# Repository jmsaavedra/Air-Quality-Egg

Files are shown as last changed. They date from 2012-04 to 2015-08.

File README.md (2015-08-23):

# Air Quality Egg

A large-scale distributed air quality network sensor device. based on the Nanode
an Arduino-compatible, Ethernet enabled microcontroller.
[airqualityegg.com](http://airqualityegg.com)

## Sensors
* temp/humidity (RHT22)
* carbon monoxide (e2v MICS-5525)
* nitrous dioxide (e2v MICS-2710)

## Notes
* auto reset feature connects digitalPin 3 to RESET pin
** this *must* be disconnected when programming the board.

## Collaborators
* [cosm.com](http://cosm.com)
* [citizensensor.cc](http://citizensensor.cc) | [jos.ph](http://jos.ph)
* [Wicked Device](http://wickeddevice.com)
* Ricardo Piedrahita, Nick Masson - UC Boulder (-link-)
* your name here

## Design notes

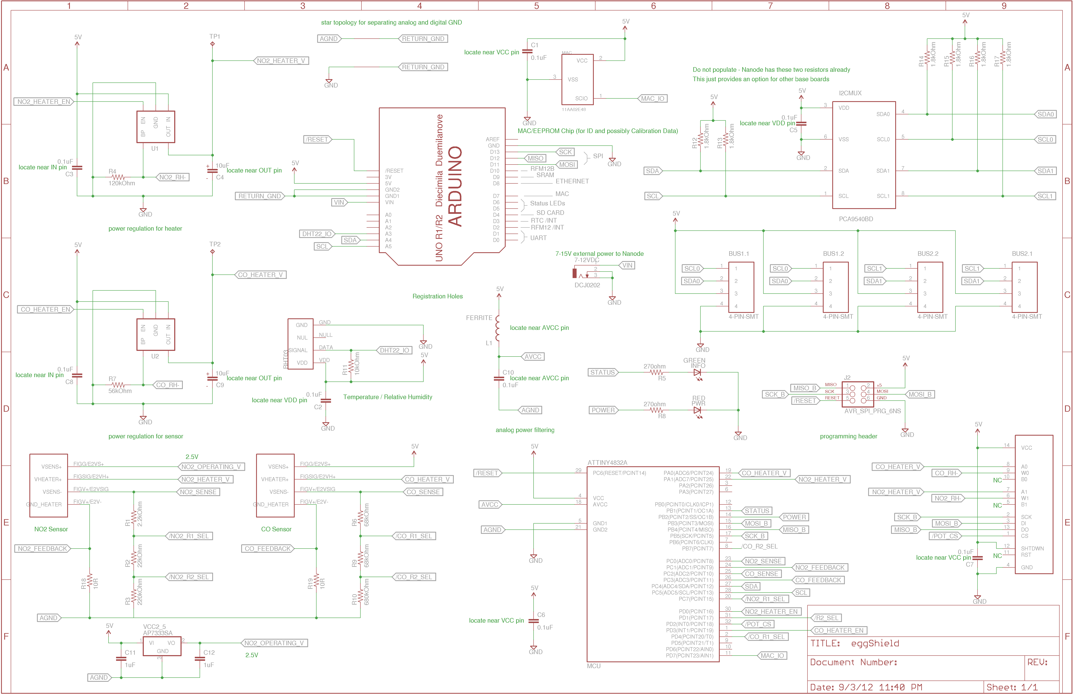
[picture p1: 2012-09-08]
.solderpad/schematic.png

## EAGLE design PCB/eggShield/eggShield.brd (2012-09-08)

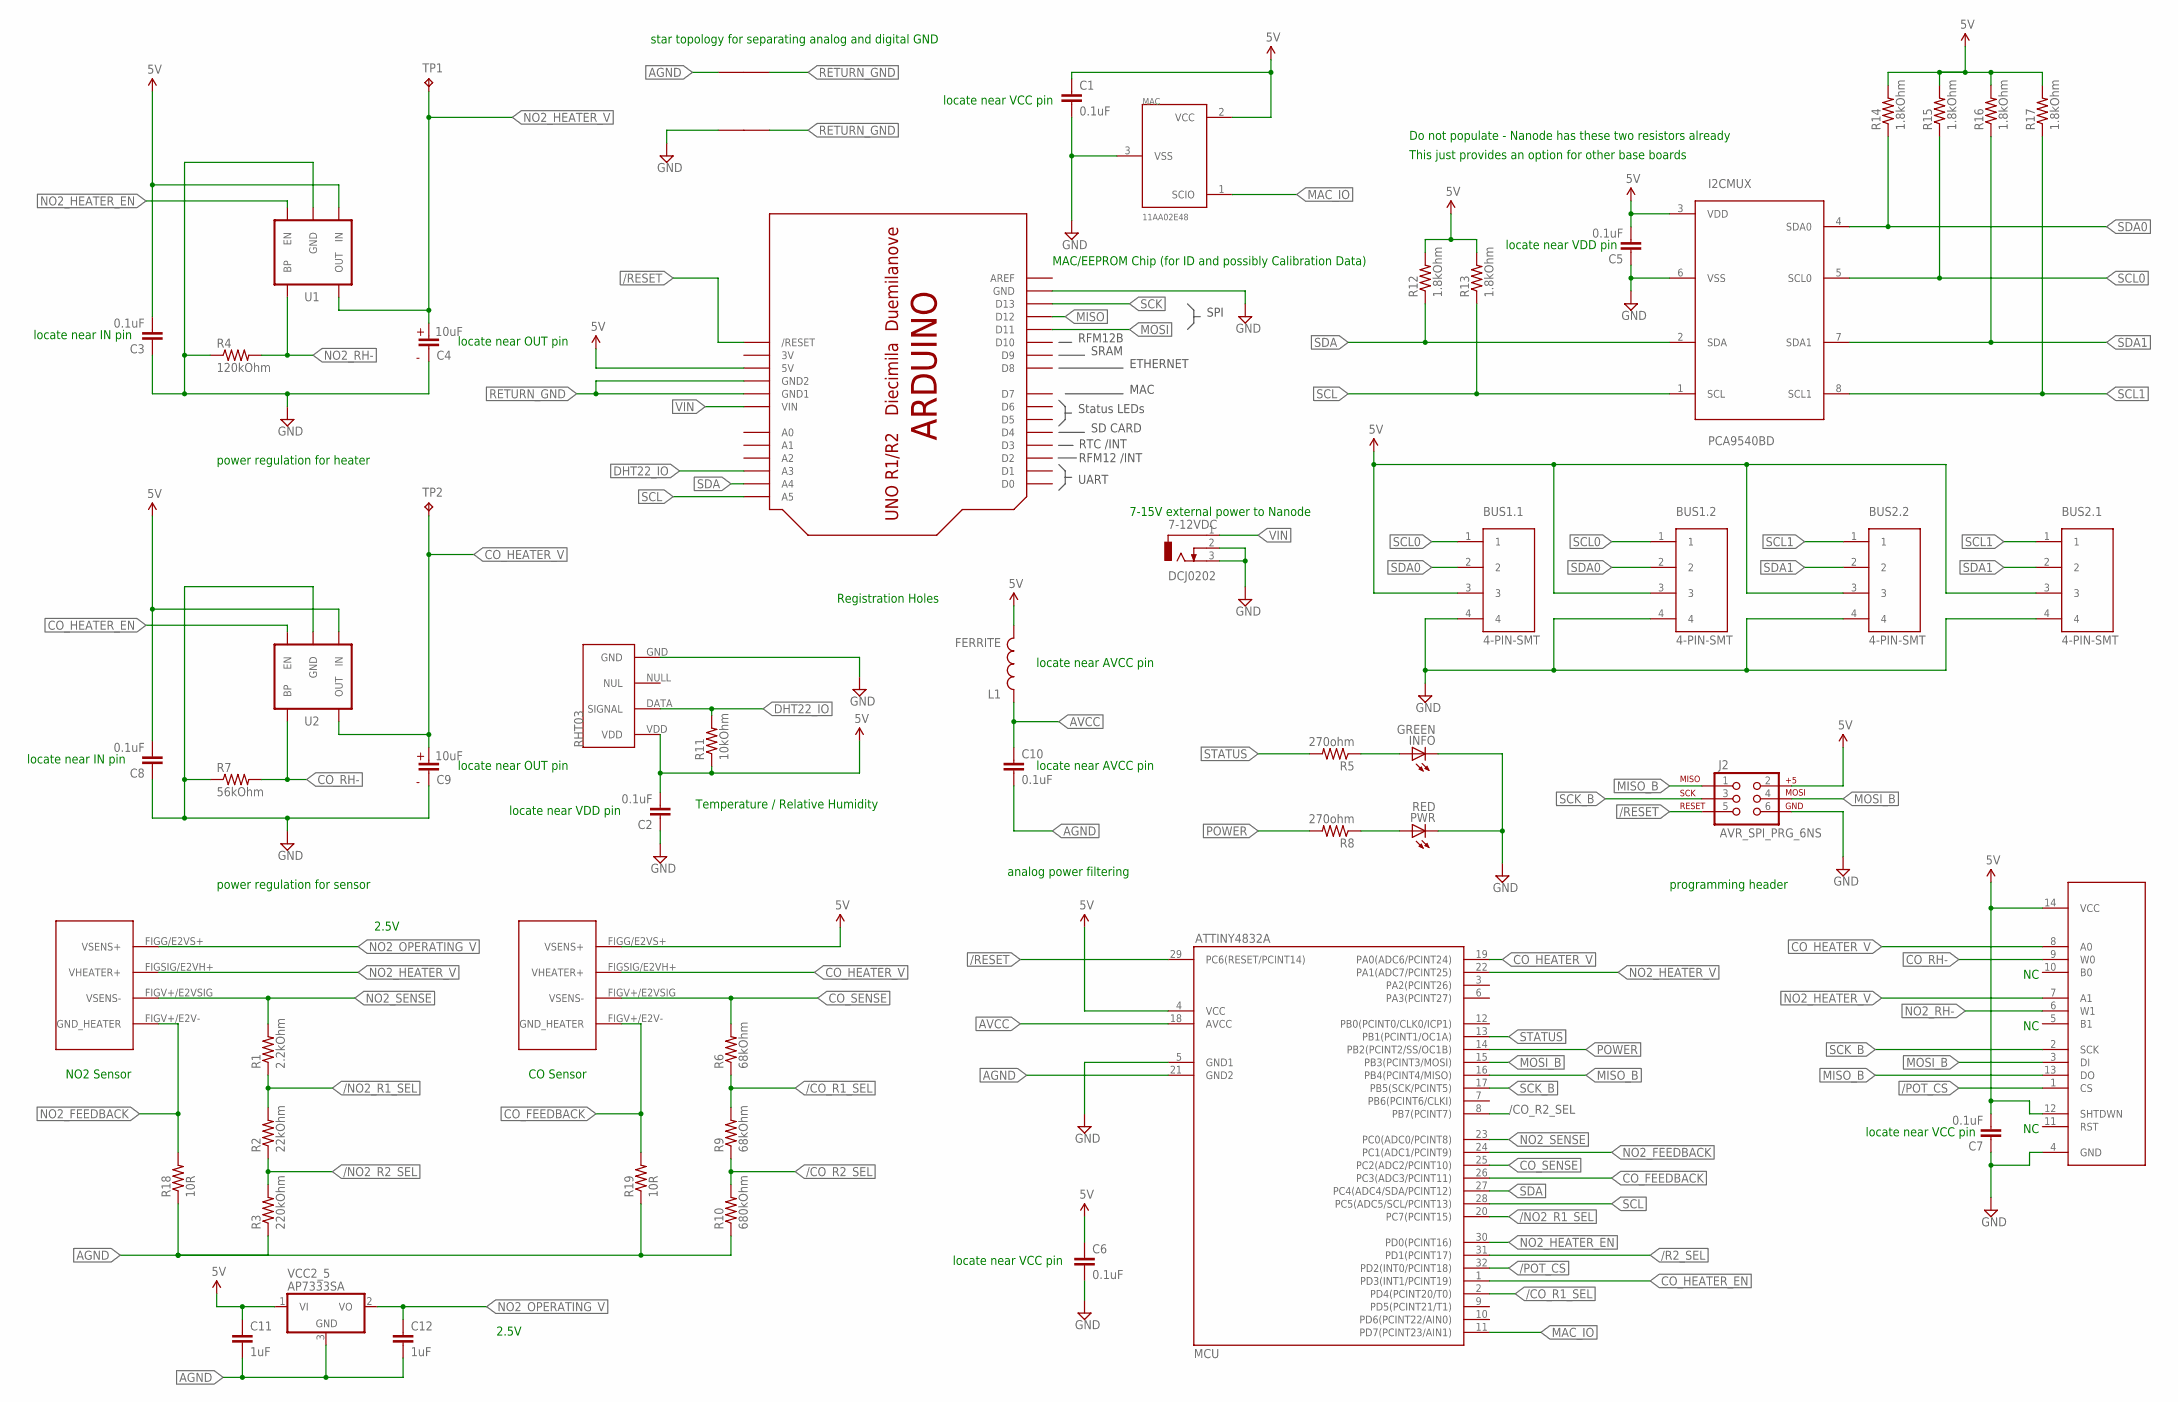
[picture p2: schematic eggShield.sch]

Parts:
7-12VDC: DCJ0202
BUS1.1, BUS1.2, BUS2.1, BUS2.2: 4-PIN-SMT; 1775470-4
C1, C2, C3, C5, C6, C7, C8, C10: 0.1uF; 0805
C4, C9: 10uF; TYPE-B_ALUMINUM_CAN
C11, C12: 1uF; 0805
CO: E2V; SR-4
DHT22: RHT03; 1X04_LOCK
I2CMUX: PCA9540BD; SO8
INFO: GREEN; CHIPLED_0805
J2: AVR_SPI_PRG_6NS; 2X3-NS
L1: FERRITE; 0805
MAC: 11AA02E48; SOT23
MCU: ATTINY4832A; TQFP32-08
N02: E2V; SR-4
PWR: RED; CHIPLED_0805
R1: 2.2kOhm; 0805
R2: 22kOhm; 0805
R3: 220kOhm; 0805
R4: 120kOhm; 0805
R5, R8: 270ohm; 0805
R6, R9: 68kOhm; 0805
R7: 56kOhm; 0805
R10: 680kOhm; 0805
R11: 10kOhm; 0805
R12, R13, R14, R15, R16, R17: 1.8kOhm; 0805
R18, R19: 10R; 0805
TP1, TP2: TPPAD1-13; P1-13
U1, U2: V_REG_LDOSMD; SOT23-5
U3: MCP42XXX; SO014
U$7: ARDUINO-NOHOLE
U$13, U$14: PLANE_COUPLER
VCC2_5: AP7333SA; SOT-23-3

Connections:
3V: U$7.3V
5V: BUS1.1.3, BUS1.2.3, BUS2.1.3, BUS2.2.3, C1.1, C2.2, C3.2, C5.2, C6.1, C7.2, C8.2, C11.1, CO.FIGG/E2VS+ (VSENS+), DHT22.VDD, I2CMUX.3 (VDD), J2.2, L1.2, MAC.2 (VCC), MCU.4 (VCC), R11.1, R12.2, R13.2, R14.2, R15.2, R16.2, R17.2, U1.1 (IN), U2.1 (IN), U3.12 (SHTDWN), U3.14 (VCC), U$7.5V, VCC2_5.1 (VI)
/CO_R1_SEL: MCU.2 (PD4(PCINT20/T0)), R6.1, R9.2
/CO_R2_SEL: MCU.8 (PB7(PCINT7)), R9.1, R10.2
/NO2_R1_SEL: MCU.20 (PC7(PCINT15)), R1.1, R2.2
/NO2_R2_SEL: R2.1, R3.2
/POT_CS: MCU.32 (PD2(INT0/PCINT18)), U3.1 (CS)
/R2_SEL: MCU.31 (PD1(PCINT17))
/RESET: J2.5, MCU.29 (PC6(RESET/PCINT14)), U$7.RESET (/RESET)
AGND: C10.2, C11.2, C12.2, MCU.21 (GND2), R3.1, R10.1, R18.1, R19.1, U$13.1, VCC2_5.3 (GND)
AVCC: C10.1, L1.1, MCU.18 (AVCC)
CO_FEEDBACK: CO.FIGV+/E2V- (GND_HEATER), MCU.26 (PC3(ADC3/PCINT11)), R19.2
CO_HEATER_EN: MCU.1 (PD3(INT1/PCINT19)), U2.3 (EN)
CO_HEATER_V: C9.P$1 (1), CO.FIGSIG/E2VH+ (VHEATER+), MCU.19 (PA0(ADC6/PCINT24)), TP2.TP, U2.5 (OUT), U3.8 (A0)
CO_RH-: R7.2, U2.4 (BP), U3.9 (W0)
CO_SENSE: CO.FIGV+/E2VSIG (VSENS-), MCU.25 (PC2(ADC2/PCINT10)), R6.2
DHT22_IO: DHT22.DATA (SIGNAL), R11.2, U$7.A3
GND: 7-12VDC.2, 7-12VDC.3, BUS1.1.4, BUS1.2.4, BUS2.1.4, BUS2.2.4, C1.2, C2.1, C3.1, C4.P$2 (2), C5.1, C6.2, C7.1, C8.1, C9.P$2 (2), DHT22.GND, I2CMUX.6 (VSS), INFO.C, J2.6, MAC.3 (VSS), MCU.5 (GND1), PWR.C, R4.1, R7.1, U1.2 (GND), U2.2 (GND), U3.4 (GND), U$7.GND, U$14.1
MAC_IO: MAC.1 (SCIO), MCU.11 (PD7(PCINT23/AIN1))
MISO: U$7.D12
MISO_B: J2.1, MCU.16 (PB4(PCINT4/MISO)), U3.13 (DO)
MOSI: U$7.D11
MOSI_B: J2.4, MCU.15 (PB3(PCINT3/MOSI)), U3.3 (DI)
unnamed: INFO.A, R5.1
unnamed: PWR.A, R8.1
NO2_FEEDBACK: MCU.24 (PC1(ADC1/PCINT9)), N02.FIGV+/E2V- (GND_HEATER), R18.2
NO2_HEATER_EN: MCU.30 (PD0(PCINT16)), U1.3 (EN)
NO2_HEATER_V: C4.P$1 (1), MCU.22 (PA1(ADC7/PCINT25)), N02.FIGSIG/E2VH+ (VHEATER+), TP1.TP, U1.5 (OUT), U3.7 (A1)
NO2_OPERATING_V: C12.1, N02.FIGG/E2VS+ (VSENS+), VCC2_5.2 (VO)
NO2_RH-: R4.2, U1.4 (BP), U3.6 (W1)
NO2_SENSE: MCU.23 (PC0(ADC0/PCINT8)), N02.FIGV+/E2VSIG (VSENS-), R1.2
POWER: MCU.14 (PB2(PCINT2/SS/OC1B)), R8.2
RETURN_GND: U$7.GND1, U$7.GND2, U$13.2, U$14.2
SCK: U$7.D13
SCK_B: J2.3, MCU.17 (PB5(SCK/PCINT5)), U3.2 (SCK)
SCL: I2CMUX.1 (SCL), MCU.28 (PC5(ADC5/SCL/PCINT13)), R13.1, U$7.A5
SCL0: BUS1.1.1, BUS1.2.1, I2CMUX.5 (SCL0), R15.1
SCL1: BUS2.1.1, BUS2.2.1, I2CMUX.8 (SCL1), R17.1
SDA: I2CMUX.2 (SDA), MCU.27 (PC4(ADC4/SDA/PCINT12)), R12.1, U$7.A4
SDA0: BUS1.1.2, BUS1.2.2, I2CMUX.4 (SDA0), R14.1
SDA1: BUS2.1.2, BUS2.2.2, I2CMUX.7 (SDA1), R16.1
STATUS: MCU.13 (PB1(PCINT1/OC1A)), R5.2
VIN: 7-12VDC.1, U$7.VIN

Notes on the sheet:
power regulation for heater
NO2 Sensor
10uF
power regulation for sensor
locate near IN pin
locate near OUT pin
CO Sensor
Temperature / Relative Humidity
locate near VDD pin
Do not populate - Nanode has these two resistors already
This just provides an option for other base boards
SPI
SRAM
ETHERNET
SD CARD
MAC
Status LEDs
RFM12B
UART
Registration Holes
locate near VCC pin
star topology for separating analog and digital GND
locate near AVCC pin
analog power filtering
2.5V
programming header
7-15V external power to Nanode
RFM12 /INT
RTC /INT
MAC/EEPROM Chip (for ID and possibly Calibration Data)

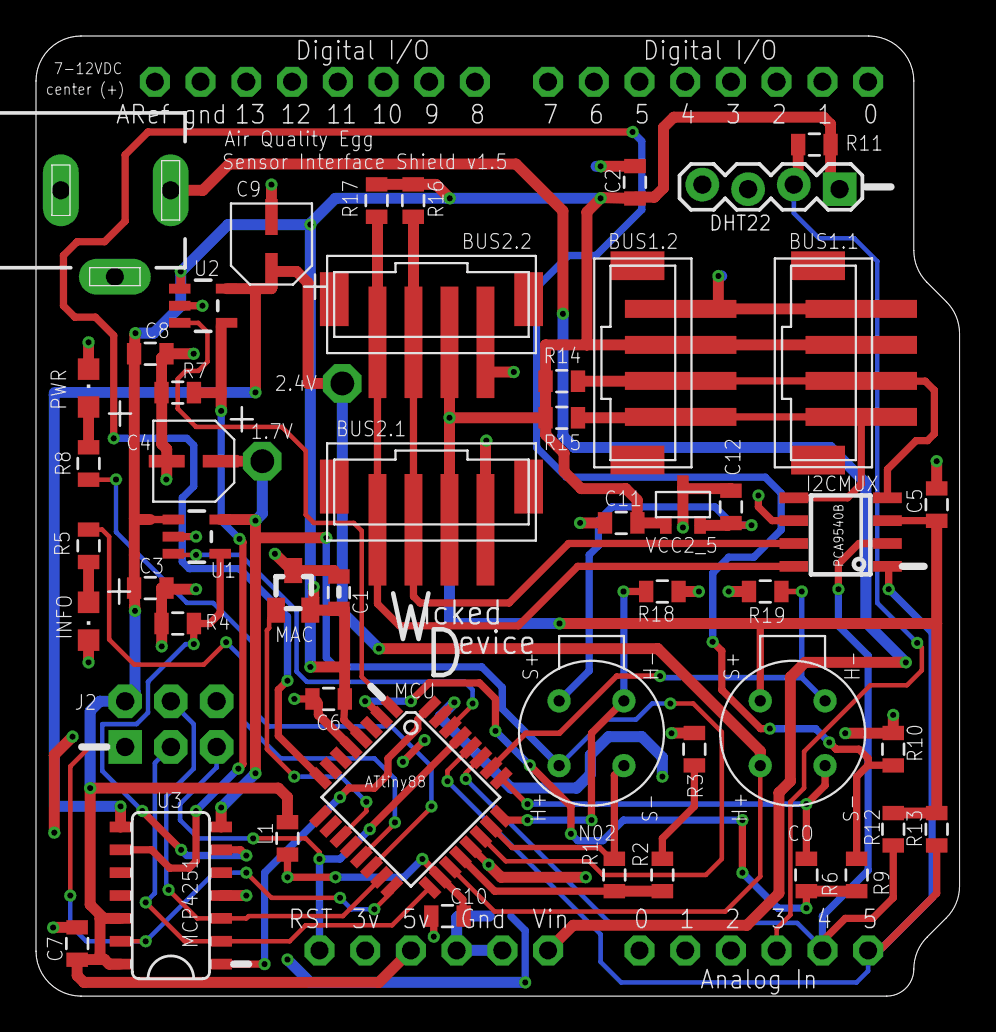
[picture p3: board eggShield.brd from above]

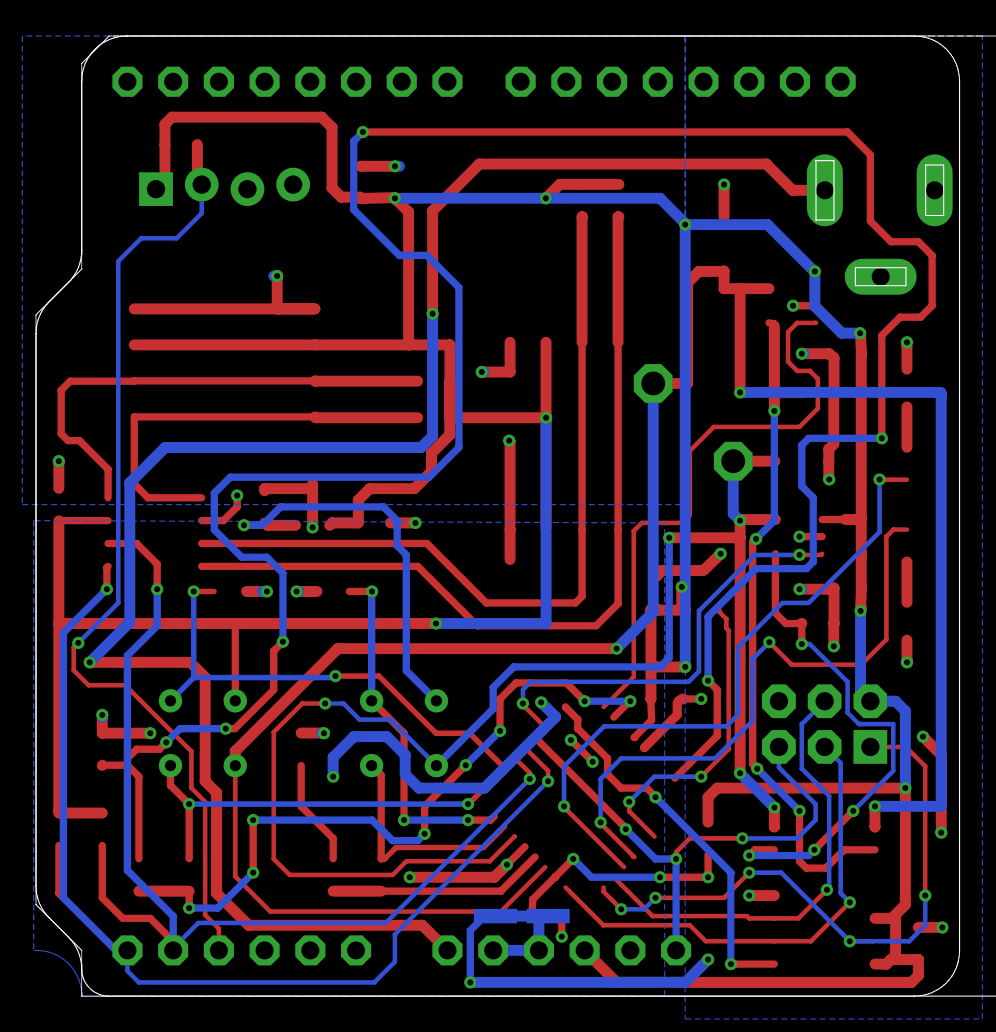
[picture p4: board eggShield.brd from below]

Board: 2 copper layers, 51.3 x 53.3 mm, 55 parts (2 on the bottom side), 38 nets.

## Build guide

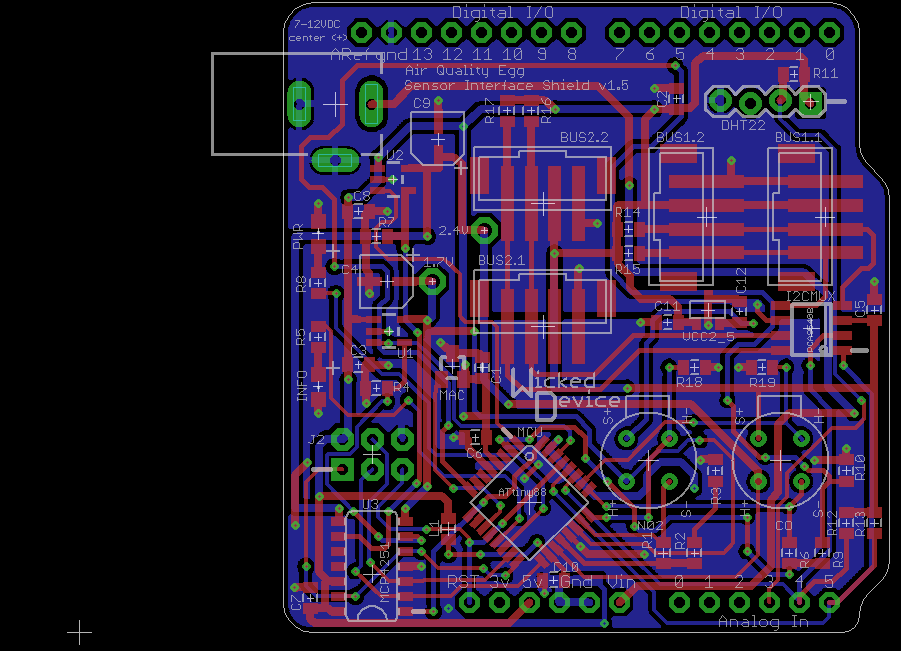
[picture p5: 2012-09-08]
.solderpad/board.png

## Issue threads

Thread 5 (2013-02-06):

Sensor doesn't reconnect without power cycling both units

yaleman, 2013-02-06:
Is there a way to fix this issue? Having to power cycle both units to get them back online seems counterintuitive.

I see from the serial logs that the sensor can seemingly know its previous base station and look for that, but it doesn't send data for some reason. Is this a known issue or a new one?

yaleman, 2021-01-08:
guess not.

Closed 2021-01-08.

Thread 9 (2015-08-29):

compile errors

grenm, 2015-08-29:
Hi, new to arduino programming, following the https://vimeo.com/58550465 Egg-3Reprogramming guide closely, the AQEBase will not compile, screen print below

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

- I am certainly doing something silly, any tips? Compile error messages below:

Arduino: 1.6.5 (Windows 7), Board: "Arduino/Genuino Uno"

In file included from AQEBase.ino:4:0:
C:\Users\ggren\Documents\Arduino\libraries\EtherCard/EtherCard.h:290:28: error: 'prog_char' has not been declared
     static void browseUrl (prog_char *urlbuf, const char *urlbuf_varpart,
                            ^
C:\Users\ggren\Documents\Arduino\libraries\EtherCard/EtherCard.h:291:28: error: 'prog_char' has not been declared
                            prog_char *hoststr, const prog_char *additionalheaderline,
                            ^
C:\Users\ggren\Documents\Arduino\libraries\EtherCard/EtherCard.h:291:54: error: 'prog_char' does not name a type
                            prog_char *hoststr, const prog_char *additionalheaderline,
                                                      ^
C:\Users\ggren\Documents\Arduino\libraries\EtherCard/EtherCard.h:291:65: error: ISO C++ forbids declaration of 'additionalheaderline' with no type [-fpermissive]
                            prog_char *hoststr, const prog_char *additionalheaderline,
                                                                 ^
C:\Users\ggren\Documents\Arduino\libraries\EtherCard/EtherCard.h:297:28: error: 'prog_char' has not been declared
     static void browseUrl (prog_char *urlbuf, const char *urlbuf_varpart,
                            ^
C:\Users\ggren\Documents\Arduino\libraries\EtherCard/EtherCard.h:298:28: error: 'prog_char' has not been declared
                            prog_char *hoststr,
                            ^
C:\Users\ggren\Documents\Arduino\libraries\EtherCard/EtherCard.h:304:27: error: 'prog_char' has not been declared
     static void httpPost (prog_char *urlbuf, prog_char *hoststr,
                           ^
C:\Users\ggren\Documents\Arduino\libraries\EtherCard/EtherCard.h:304:46: error: 'prog_char' has not been declared
     static void httpPost (prog_char *urlbuf, prog_char *hoststr,
                                              ^
C:\Users\ggren\Documents\Arduino\libraries\EtherCard/EtherCard.h:305:27: error: 'prog_char' has not been declared
                           prog_char *additionalheaderline, const char *postval,
                           ^
C:\Users\ggren\Documents\Arduino\libraries\EtherCard/EtherCard.h:447:34: error: 'prog_char' does not name a type
     static bool dnsLookup (const prog_char* name, bool fromRam =false);
                                  ^
C:\Users\ggren\Documents\Arduino\libraries\EtherCard/EtherCard.h:447:45: error: ISO C++ forbids declaration of 'name' with no type [-fpermissive]
     static bool dnsLookup (const prog_char* name, bool fromRam =false);
                                             ^
In file included from C:\Program Files (x86)\Arduino\hardware\arduino\avr\cores\arduino/Arduino.h:28:0,
                 from C:\Users\ggren\Documents\Arduino\libraries\AQERF_Base/AQERF_Base.h:26,
                 from AQEBase.ino:1:
Nanode:10: error: variable 'website' must be const in order to be put into read-only section by means of '__attribute__((progmem))'
Nanode.ino: In function 'void setupNanode()':
Nanode:50: error: no matching function for call to 'EtherCard::dnsLookup(char [15])'
Nanode.ino:50:31: note: candidate is:
In file included from AQEBase.ino:4:0:
C:\Users\ggren\Documents\Arduino\libraries\EtherCard/EtherCard.h:447:17: note: static bool EtherCard::dnsLookup(const int*, bool)
     static bool dnsLookup (const prog_char* name, bool fromRam =false);
                 ^
C:\Users\ggren\Documents\Arduino\libraries\EtherCard/EtherCard.h:447:17: note:   no known conversion for argument 1 from 'char [15]' to 'const int*'
In file included from C:\Program Files (x86)\Arduino\hardware\arduino\avr\cores\arduino/Arduino.h:28:0,
                 from C:\Users\ggren\Documents\Arduino\libraries\AQERF_Base/AQERF_Base.h:26,
                 from AQEBase.ino:1:
Provision.ino: At global scope:
Provision:9: error: variable 'website' must be const in order to be put into read-only section by means of '__attribute__((progmem))'
Provision.ino: In function 'void doProvisioning()':
Provision:173: error: no matching function for call to 'EtherCard::browseUrl(const char*, char [52], char [15], void (&)(byte, word, word))'
Provision.ino:173:92: note: candidates are:
In file included from AQEBase.ino:4:0:
C:\Users\ggren\Documents\Arduino\libraries\EtherCard/EtherCard.h:290:17: note: static void EtherCard::browseUrl(int*, const char*, int*, const int*, void (*)(uint8_t, uint16_t, uint16_t))
     static void browseUrl (prog_char *urlbuf, const char *urlbuf_varpart,
                 ^
C:\Users\ggren\Documents\Arduino\libraries\EtherCard/EtherCard.h:290:17: note:   candidate expects 5 arguments, 4 provided
C:\Users\ggren\Documents\Arduino\libraries\EtherCard/EtherCard.h:297:17: note: static void EtherCard::browseUrl(int*, const char*, int*, void (*)(uint8_t, uint16_t, uint16_t))
     static void browseUrl (prog_char *urlbuf, const char *urlbuf_varpart,
                 ^
C:\Users\ggren\Documents\Arduino\libraries\EtherCard/EtherCard.h:297:17: note:   no known conversion for argument 1 from 'const char*' to 'int*'
In file included from C:\Program Files (x86)\Arduino\hardware\arduino\avr\cores\arduino/Arduino.h:28:0,
                 from C:\Users\ggren\Documents\Arduino\libraries\AQERF_Base/AQERF_Base.h:26,
                 from AQEBase.ino:1:
Sensors.ino: At global scope:
Sensors:10: error: variable 'website' must be const in order to be put into read-only section by means of '__attribute__((progmem))'
variable 'website' must be const in order to be put into read-only section by means of '__attribute__((progmem))'

  This report would have more information with
  "Show verbose output during compilation"
  enabled in File > Preferences.

WickedDevice, 2015-08-29:
Probably need to be using Arduino 1.0.6.

Regards,
Vic
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

WickedDevice, 2015-08-29:
Also be aware that is the code base for the version 1 air quality egg only.

This article describes how to compile for version 2 eggs.

http://shop.wickeddevice.com/2015/08/26/re-programming-an-air-quality-egg-v2/

Kind Regards,
Vic
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

fraguada, 2018-01-01:
Just for completeness, the code in question compiled in Arduino 1.0.5 for macOS found here: https://www.arduino.cc/en/Main/OldSoftwareReleases#1.0.x

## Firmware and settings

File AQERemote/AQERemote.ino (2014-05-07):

#include <Wire.h>
#include <EggBus.h>
#include <AQERF_Remote.h>
#include <RF12.h>
#include <NanodeMAC.h>
#include <SoftReset.h>
#include <avr/wdt.h>

#define FIRMWARE_REVISION 0x21

#define SENSOR_PACKET_DELAY 5000L
#define TRANSMIT_STATE_SEND_TEMPERATURE 1
#define TRANSMIT_STATE_SEND_HUMIDITY    2
#define TRANSMIT_STATE_POLL_EGG_BUS     3
#define TRANSMIT_STATE_WAITING          4
static uint8_t transmit_state = TRANSMIT_STATE_WAITING;
char sensor_type_temperature[]  = "Temperature";
char sensor_units_temperature[] = "deg C";
char sensor_type_humidity[]     = "Humidity";   
char sensor_units_humidity[]    = "%";   
uint8_t eggbus_sensor_index     = 0;
char feed_name[32] = {0}; 

// read your MAC address
static uint8_t mymac[6] = {0,0,0,0,0,0};
NanodeMAC mac(mymac);
EggBus eggBus;

#define SEND_RAW        0
#define SEND_CALCULATED 1
#define SEND_R0         2

byte send_type = SEND_RAW;

// create an AQERF_Base object to handle the RF Link
// informing it what the unit MAC address is
AQERF_Remote rflink(mymac); 

void printMAC(uint8_t * mac);

// support variables
byte first_time = 1;
long previous_millis = 0;
int need_to_send = 0;

void setup(){
    randomSeed(analogRead(0));
    
    rflink.setTransmitInterval(120000L); // transmit every two minutes
    
    Serial.begin(115200);
    Serial.println(F("\n[Air Quality Egg - Remote - v2.02]"));
    Serial.print(F("Unit Address: "));
    printlnMAC(mymac);
    Serial.print(F("Last Paired Base: "));
    printlnMAC(rflink.getBaseStationAddress());

    for(;;){ // until some condition results in a break
        if(rflink.pair()){
            Serial.println(F("Pairing Successful"));
            Serial.print(F("Base Station Address: "));
            printlnMAC(rflink.getBaseStationAddress());

            // after pairing succeeds, ensure that the pairing phase is complete before 
            // proceeding to runtime behavior (i.e. loop)
            delay(AQERF_PAIRING_DURATION_MS); 

            break; // go to loop
        }
        else{
            Serial.println(F("Pairing Failed"));
            // check to see if we already know who are base station is from EEPROM
            // if we do, then use it and proceed to runtime behavior (i.e. loop)
            if(rflink.previouslyPaired()){
                Serial.println(F("Assuming previously paired Base Station"));
                break;
            }
            else{
                // otherwise fall through and re-attempt pairing
                Serial.println(F("Retrying")); 
            }
        }
    }
    
    previous_millis = millis();
}  

void loop(){
    unsigned long currentMillis = millis(); 

    if((first_time == 1) || (currentMillis - previous_millis > rflink.getTransmitInterval())) {             

      if(transmit_state != TRANSMIT_STATE_WAITING){
          Serial.println(F("Something is taking longer than expected, Resetting"));
          Serial.flush();
          delay(1000);
          soft_restart(); 
        }
                
        first_time = 0;
        previous_millis = currentMillis;              
        need_to_send = 0;   
        transmit_state = TRANSMIT_STATE_SEND_TEMPERATURE;
        
        eggBus.init();        
    }
    
    if(need_to_send == 0){
      switch(transmit_state){
      case TRANSMIT_STATE_SEND_TEMPERATURE:
        setupTemperaturePacket();
        need_to_send = 1;    
        transmit_state = TRANSMIT_STATE_SEND_HUMIDITY;
        break;
      case TRANSMIT_STATE_SEND_HUMIDITY:
        setupHumidityPacket();
        need_to_send = 1;    
        eggbus_sensor_index = 0;
        if(eggBus.next()){
          transmit_state = TRANSMIT_STATE_POLL_EGG_BUS;
        }
        else{
          transmit_state = TRANSMIT_STATE_WAITING;
        }
        break;
      case TRANSMIT_STATE_POLL_EGG_BUS:
        if(eggbus_sensor_index < eggBus.getNumSensors()){ // there are more sensors at the current address
          if(SEND_RAW == send_type){
            setupEggBusPacketRaw();             
            send_type = SEND_R0;          
          }
          else if(SEND_R0 == send_type){
            setupEggBusPacketR0();             
            send_type = SEND_CALCULATED;             
          }
          else{
            setupEggBusPacket();                                         
            send_type = SEND_RAW;
            eggbus_sensor_index++;            
          }
          
          need_to_send = 1;          
        }
        else if(eggBus.next()){ // there are more sensors on the bus
          eggbus_sensor_index = 0;
        }
        else{ // there are no sensors left on the bus
          need_to_send = 0;
          transmit_state = TRANSMIT_STATE_WAITING;
        }
        break;
      case TRANSMIT_STATE_WAITING:
        // nothing to do here ...
        break;
      default: 
        Serial.print(F("Transmit State = "));
        Serial.print(transmit_state);
        Serial.println(F("... Inconceivable!"));
        break;    
      }
    }

    if(rflink.clearToSend() && need_to_send){
        
        // transmit the packet
        rflink.transmit();
    
        need_to_send = 0;
        Serial.print(F("Transmitted Packet: "));
        Serial.println(feed_name);
        
        delay(SENSOR_PACKET_DELAY);
    }     
}

void printlnMAC(uint8_t * mac){
    for(uint8_t i = 0; i < 6; i++){
        if(mac[i] < 10) Serial.print(F("0"));
        Serial.print(mac[i], HEX);
        if(i != 5){        
            Serial.print(F(":"));
        }
    }
    Serial.println();

}

void setupTemperaturePacket(){
    memcpy(feed_name, 0, 32);    
    strncpy(feed_name, sensor_type_temperature, 20);  
    rflink.setPacketType(AQERF_PACKET_TYPE_REMOTE_STATION_DATUM);
    rflink.setRemoteFirmwareVersion(FIRMWARE_REVISION);
    rflink.setRemoteStationAddress(mymac);
    rflink.setSourceSensorAddress(mymac);
    rflink.setSensorIndex(0);
    rflink.setSensorType(sensor_type_temperature);
    rflink.setSensorUnits(sensor_units_temperature);
    rflink.setSensorValue(getTemperature()); 
}

void setupHumidityPacket(){
    memcpy(feed_name, 0, 32);    
    strncpy(feed_name, sensor_type_humidity, 20);  
    rflink.setPacketType(AQERF_PACKET_TYPE_REMOTE_STATION_DATUM);
    rflink.setRemoteFirmwareVersion(FIRMWARE_REVISION);
    rflink.setRemoteStationAddress(mymac);
    rflink.setSourceSensorAddress(mymac);
    rflink.setSensorIndex(1);
    rflink.setSensorType(sensor_type_humidity);
    rflink.setSensorUnits(sensor_units_humidity);
    rflink.setSensorValue(getHumidity());  
}

void setupEggBusPacket(){
    float sensor_val = 0;
    memcpy(feed_name, 0, 32);    
    strncpy(feed_name, eggBus.getSensorType(eggbus_sensor_index), 20);
    rflink.setPacketType(AQERF_PACKET_TYPE_REMOTE_STATION_DATUM);
    rflink.setRemoteFirmwareVersion(eggBus.getFirmwareVersion());
    rflink.setRemoteStationAddress(mymac);
    rflink.setSourceSensorAddress(eggBus.getSensorAddress());
    rflink.setSensorIndex(eggbus_sensor_index);
    rflink.setSensorType(eggBus.getSensorType(eggbus_sensor_index));
    rflink.setSensorUnits(eggBus.getSensorUnits(eggbus_sensor_index));
    sensor_val = eggBus.getSensorValue(eggbus_sensor_index);
    if(sensor_val < 0) sensor_val = 0;
    rflink.setSensorValue(sensor_val);    
}

void setupEggBusPacketRaw(){ 
    char * ohms = "ohms";
    
    strncpy(feed_name, eggBus.getSensorType(eggbus_sensor_index), 20);
    strcat(feed_name, "_raw");
    
    rflink.setPacketType(AQERF_PACKET_TYPE_REMOTE_STATION_DATUM);
    rflink.setRemoteFirmwareVersion(eggBus.getFirmwareVersion());
    rflink.setRemoteStationAddress(mymac);
    rflink.setSourceSensorAddress(eggBus.getSensorAddress());
    rflink.setSensorIndex(eggbus_sensor_index);
    rflink.setSensorType(feed_name);
    rflink.setSensorUnits(ohms);
    rflink.setSensorValue((uint32_t) eggBus.getSensorResistance(eggbus_sensor_index));         
}

void setupEggBusPacketR0(){ 
    char * ohms = "ohms";
    uint32_t resistance = eggBus.getSensorR0(eggbus_sensor_index);
    memcpy(feed_name, 0, 32);
    
    strncpy(feed_name, eggBus.getSensorType(eggbus_sensor_index), 20);
    strcat(feed_name, "_r0");
    
    rflink.setPacketType(AQERF_PACKET_TYPE_REMOTE_STATION_DATUM);
    rflink.setRemoteFirmwareVersion(eggBus.getFirmwareVersion());
    rflink.setRemoteStationAddress(mymac);
    rflink.setSourceSensorAddress(eggBus.getSensorAddress());
    rflink.setSensorIndex(eggbus_sensor_index);
    rflink.setSensorType(feed_name);
    rflink.setSensorUnits(ohms);
    rflink.setSensorValue(resistance);         
}

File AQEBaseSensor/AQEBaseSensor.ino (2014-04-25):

#include <Wire.h>
#include <EggBus.h>
#include <NanodeMAC.h>
#include <SoftReset.h>
#include <avr/wdt.h>

#define SENSOR_PACKET_DELAY  5000L
#define FORCED_RESET_TIME_MS 600000L

#define TRANSMIT_STATE_SEND_TEMPERATURE 1
#define TRANSMIT_STATE_SEND_HUMIDITY    2
#define TRANSMIT_STATE_POLL_EGG_BUS     3
#define TRANSMIT_STATE_WAITING          4
static uint8_t transmit_state = TRANSMIT_STATE_WAITING;  
uint8_t eggbus_sensor_index     = 0;

// read your MAC address
static uint8_t mymac[6] = {0,0,0,0,0,0};
NanodeMAC mac(mymac);
EggBus eggBus;

#define SEND_RAW        0
#define SEND_CALCULATED 1
#define SEND_R0         2
byte send_type = SEND_RAW;

void printMAC(uint8_t * mac);

// support variables
long cosmPostPreviousMillis = 0;
long cosmPostInterval = 150000L;
long cosmDelayPreviousMillis = 0;
long cosmDelayInterval = 5000L;
long heartbeatPreviousMillis = 0;
long heartbeatInterval = 500L;
byte need_to_send = 0;
byte clear_to_send = 1;

void setup(){
    randomSeed(analogRead(0));

    Serial.begin(115200);
    Serial.println(F("\n[Air Quality Egg - Base Sensor - v2.03]"));
    Serial.print("Unit Address: ");
    printlnMAC(mymac);    
    cosmPostPreviousMillis = 71243411;
    
    setupNanode();
        
}  

void loop(){
    unsigned long currentMillis = millis(); 
    
    loopNanode();

    if(currentMillis - cosmPostPreviousMillis > cosmPostInterval) {
        if(transmit_state != TRANSMIT_STATE_WAITING){
          Serial.println(F("Something is taking longer than expected, Resetting"));
          Serial.flush();
          delay(1000);
          soft_restart(); 
        }
        
        Serial.println(F("Kicking off transmit cycle"));
        cosmPostPreviousMillis = currentMillis;              
        need_to_send = 0;   
        transmit_state = TRANSMIT_STATE_SEND_TEMPERATURE;
        
        eggBus.init();        
    }
    
    if(currentMillis - heartbeatPreviousMillis > heartbeatInterval){
      //Serial.print(transmit_state);
      heartbeatPreviousMillis = currentMillis;
    }    
    
    if(need_to_send == 0){
      switch(transmit_state){
      case TRANSMIT_STATE_SEND_TEMPERATURE:
        sendTemperature();
        need_to_send = 1; 
        Serial.print(millis()); 
        Serial.println(F(" Sent Temperature"));
        transmit_state = TRANSMIT_STATE_SEND_HUMIDITY;
        break;
      case TRANSMIT_STATE_SEND_HUMIDITY:
        sendHumidity();
        need_to_send = 1;          
        eggbus_sensor_index = 0;
        Serial.print(millis());         
        Serial.println(F(" Sent Humidity"));        
        if(eggBus.next()){            
          transmit_state = TRANSMIT_STATE_POLL_EGG_BUS;
        }
        else{
          transmit_state = TRANSMIT_STATE_WAITING;
        }
        break;
      case TRANSMIT_STATE_POLL_EGG_BUS:
        if(eggbus_sensor_index < eggBus.getNumSensors()){ // there are more sensors at the current address
          if(SEND_RAW == send_type){
            sendEggBus(SEND_RAW); 
            Serial.print(millis());             
            Serial.print(F(" Sent Egg Bus Raw :: "));            
            Serial.println(eggBus.getSensorType(eggbus_sensor_index));
            send_type = SEND_R0;          
          }
          else if(SEND_R0 == send_type){
            sendEggBus(SEND_R0); 
            Serial.print(millis());             
            Serial.print(F(" Sent Egg Bus R0 :: "));            
            Serial.println(eggBus.getSensorType(eggbus_sensor_index));
            send_type = SEND_CALCULATED;             
          }
          else{
            sendEggBus(SEND_CALCULATED); 
            Serial.print(millis());             
            Serial.print(F(" Sent Egg Bus Calculated :: "));            
            Serial.println(eggBus.getSensorType(eggbus_sensor_index));            
            send_type = SEND_RAW;
            eggbus_sensor_index++;            
          }
          
          need_to_send = 1;          
        }
        else if(eggBus.next()){ // there are more sensors on the bus
          eggbus_sensor_index = 0;
          need_to_send = 1;    
        }
        else{ // there are no sensors left on the bus
          need_to_send = 0;
          transmit_state = TRANSMIT_STATE_WAITING;
        }
        break;
      case TRANSMIT_STATE_WAITING:
        // reset after about 10 minutes
        if(currentMillis > FORCED_RESET_TIME_MS){
           Serial.println(F("Time for our regularly scheduled Restart!"));
           delay(1000);
           soft_restart(); 
        }
        
        // nothing else to do here ...
        break;
      default: 
        Serial.print(F("Transmit State = "));
        Serial.print(transmit_state);
        Serial.println(F("... Inconceivable!"));
        break;    
      }
    }
    

    // clear to send condition
    if((clear_to_send == 0) && (currentMillis - cosmDelayPreviousMillis > cosmDelayInterval)){        
      clear_to_send = 1;
      cosmDelayPreviousMillis = currentMillis;
    }  

    if(clear_to_send && need_to_send){
      
      // transmit the packet
      postSensorData();  
      Serial.print(millis());       
      Serial.println(F(" Posted Sensor Data"));
      Serial.println();
      need_to_send = 0;
      clear_to_send = 0;
      cosmDelayPreviousMillis = currentMillis;      
    }     
    
    if(haventHeardFromCosmLately()){
      Serial.println(F("Too Long Since Last Response From Cosm, Resetting"));
      delay(1000);
      soft_restart(); 
    }    
    
    checkCosmReply();    
}

void printlnMAC(uint8_t * mac){
    for(uint8_t i = 0; i < 6; i++){
        if(mac[i] < 10) Serial.print(F("0"));
        Serial.print(mac[i], HEX);
        if(i != 5){        
            Serial.print(F(":"));
        }
    }
    Serial.println();
}

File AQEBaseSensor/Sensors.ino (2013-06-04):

/* sensor vars and read functions */
#include <EtherCard.h>
#include <SoftReset.h>
#include <avr/wdt.h>
#include <DHT.h>
#include <string.h>
#include "MemoryLocations.h" 

#define AQE_BASESENSOR_FIRMWARE_VERSION 0x22

extern char website[] PROGMEM;
extern uint8_t eggbus_sensor_index;

long previousCosmResponseTimestamp = 0;
const long TOO_LONG_FOR_COSM_RESPONSE = 600000; // 10 minutes

Stash stash;
static byte tcp_session;

#define DHTPIN 17
#define DHTTYPE DHT22
DHT dht(DHTPIN, DHTTYPE);

void sensorSetup(){
  //Serial.println("--- DHT22 BEGIN ---");
  dht.begin(); 
  delay(500);
}

//--------- DHT22 humidity ---------
float getHumidity(){
  float h = dht.readHumidity();
  if (isnan(h)){
    //failed to get reading from DHT    
    delay(2500);
    h = dht.readHumidity();
    if(isnan(h)){
      return -1; 
    }
  } 
  return h;
}

//--------- DHT22 temperature ---------
float getTemperature(){
  float t = dht.readTemperature();
  if (isnan(t)){
    //failed to get reading from DHT
    delay(2500);
    t = dht.readTemperature();
    if(isnan(t)){
      return -1; 
    }
  } 
  return t;
}

char current_sensor_type[16] = {0};
char current_sensor_units[16] = {0};
uint8_t current_sensor_address[6] = {0};
float current_sensor_value;
uint8_t current_sensor_index;
uint8_t current_firmware_version;

void postSensorData(){  
  byte sd = stash.create();  
  char temp[64] = {0};
  char temp2[8] = {0};
  char delimiter[2] = "_";
  boolean isRaw = false;
  boolean isR0 = false;  
  int sensor_type_length = strlen(current_sensor_type);
  strcat(temp, current_sensor_type);
  strcat(temp, delimiter);
  stringConvertMAC(current_sensor_address, temp + sensor_type_length + 1,  '-');
  strcat(temp, delimiter);
  itoa(current_sensor_index, temp2, 10);
  strcat(temp, temp2);
  
  stash.print(F("{\"datastreams\":[{\"id\": \""));
  stash.print(temp);
  stash.print(F("\",\"current_value\":\""));
  stash.print(current_sensor_value, 8);
  stash.print(F("\",\"tags\":[\"aqe:sensor_type="));

  if(strstr_P(current_sensor_type, PSTR("_raw")) != NULL){
    memset(temp, 0, 64);
    strncpy(temp, current_sensor_type, strlen(current_sensor_type) - 4); // always ends in "_raw" if it has it
    stash.print(temp);    
    isRaw = true;    
  }
  else if(strstr_P(current_sensor_type, PSTR("_r0")) != NULL){
    memset(temp, 0, 64);
    strncpy(temp, current_sensor_type, strlen(current_sensor_type) - 3); // always ends in "_r0" if it has it
    stash.print(temp);    
    isR0 = true;     
  }
  else{
    stash.print(current_sensor_type);
  }  
  
  stash.print(F("\",\"aqe:sensor_address="));
  memset(temp, 0, 64);
  stringConvertMAC(current_sensor_address, temp, ':');
  stash.print(temp);
  
  stash.print(F("\",\"aqe:sensor_index="));
  stash.print(current_sensor_index);  
  
  stash.print(F("\",\"aqe:firmware_version="));
  stash.print(current_firmware_version);    
  
  stash.print(F("\",\"aqe:data_origin="));  
  if(isRaw){
    stash.print(F("raw"));
  }
  else if(isR0){
    stash.print(F("r0"));
  }
  else{
    stash.print(F("computed"));    
  }
  
  stash.print(F("\"],\"unit\":{\"label\":\""));
  stash.print(current_sensor_units);
  stash.print(F("\",\"symbol\":\""));
  stash.print(current_sensor_units);
  stash.print(F("\"}}]}"));
 
  stash.save();
  
  Serial.println(F("Preparing stash"));  
  Stash::prepare(PSTR("PUT http://$F/v2/feeds/$E.json HTTP/1.0" "\r\n"
    "Host: $F" "\r\n"
    "X-ApiKey: $E" "\r\n"
    "Content-Length: $D" "\r\n"
    "\r\n"
    "$H"),
  website, 
  (const void *) FEED_ID_EEPROM_ADDRESS, 
  website, 
  (const void *) API_KEY_EEPROM_ADDRESS, 
  stash.size(), 
  sd);

  Serial.println(F("Sending data to Cosm"));
  
  tcp_session = ether.tcpSend();  
  Serial.print(F("Data sent for "));  
  Serial.println(current_sensor_type);
}

void addressToString(uint8_t * address, char * target, char delimiter){
  uint8_t target_index = 0;
  for(uint8_t jj = 0; jj < 6; jj++){
    snprintf_P(target + target_index, 3, PSTR("%02X"), address[jj]);
    target_index+=2;
    if(jj != 5 ) target[target_index++] = delimiter;
  }
}

uint8_t checkCosmReply(){
  const char *reply = ether.tcpReply(tcp_session);
  if(reply != 0){
    Serial.println(F(">>> RESPONSE RECEIVED ---"));
    markCosmResponse();
    return 1;
  }  
  return 0;
}

void stringConvertMAC(uint8_t * mac, char * buf, char delimiter){
  for(uint8_t ii = 0; ii < 6; ii++){
    convertByteArrayToAsciiHex(mac + ii, buf + 3*ii, 1);
    if(ii == 5) buf[3*ii+2] = '\0';
    else buf[3*ii+2] = delimiter;
  }
}

boolean haventHeardFromCosmLately(){
  unsigned long currentMillis = millis();  
  if((currentMillis - previousCosmResponseTimestamp) > TOO_LONG_FOR_COSM_RESPONSE){
    return true; 
  }
  return false; 
}

void markCosmResponse(){
   previousCosmResponseTimestamp = millis();

}

void clearDataVariables(){
  memset(current_sensor_type, 0, 16);
  memset(current_sensor_units, 0, 16);
  memset(current_sensor_address, 0, 6);
  current_sensor_value = 0;
  current_sensor_index = 0;
  current_firmware_version = 0;
}

void sendTemperature(){
  clearDataVariables();
  strcpy_P(current_sensor_type, PSTR("Temperature"));
  strcpy_P(current_sensor_units, PSTR("deg C"));
  memcpy(current_sensor_address, mymac, 6);
  current_sensor_value = getTemperature();
  current_sensor_index = 1; 
  current_firmware_version = AQE_BASESENSOR_FIRMWARE_VERSION;
}

void sendHumidity(){
  clearDataVariables();
  strcpy_P(current_sensor_type, PSTR("Humidity"));
  strcpy_P(current_sensor_units, PSTR("%"));
  memcpy(current_sensor_address, mymac, 6);
  current_sensor_value = getHumidity();
  current_sensor_index = 0; 
  current_firmware_version = AQE_BASESENSOR_FIRMWARE_VERSION;
}

void sendEggBus(uint8_t sendType){
  clearDataVariables();
  
  strcpy(current_sensor_type, eggBus.getSensorType(eggbus_sensor_index));
  memcpy(current_sensor_address, eggBus.getSensorAddress(), 6);
  current_sensor_index = eggbus_sensor_index; 
  current_firmware_version = eggBus.getFirmwareVersion();  
  
  if(sendType == SEND_RAW){
      strcpy_P(current_sensor_units, PSTR("ohms"));
      strcat_P(current_sensor_type, PSTR("_raw"));
      current_sensor_value = (uint32_t) eggBus.getSensorResistance(eggbus_sensor_index);
  }
  else if(sendType == SEND_R0){
      strcpy_P(current_sensor_units, PSTR("ohms"));
      strcat_P(current_sensor_type, PSTR("_r0"));
      current_sensor_value = eggBus.getSensorR0(eggbus_sensor_index);    
  }
  else{
      strcpy(current_sensor_units, eggBus.getSensorUnits(eggbus_sensor_index));   
      current_sensor_value = eggBus.getSensorValue(eggbus_sensor_index);
  }
}

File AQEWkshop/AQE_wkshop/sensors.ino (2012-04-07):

/* sensor vars and read functions */

//debounce time (milliseconds) between each analog sensor reading
const int sensorDebounceTime = 15;

int tmp102Address = 0x48; //temp sensor 2-wire address

CS_MQ7 MQ7(4);  //sensor "tog" pin on 4

void readSensors(){
  //sensors
  Serial.println("reading sensors");
  currNo2 = getNo2();
  delay(sensorDebounceTime);
  currCo = getCO();
  delay(sensorDebounceTime);
  currQuality = getQuality();
  delay(sensorDebounceTime);
  currHumidity = getHumidity();
  delay(sensorDebounceTime);
  currTemp = getTemperature();
  delay(sensorDebounceTime);

  MQ7.CoPwrCycler(); //for CO sensor power cycling
}

//--------- e2v MiCS-2170 NO2 sensor ---------
int getNo2(){
  int thisReading = 10;

  //set reference voltage to 3.3 here?
  thisReading = analogRead(No2SensorPin);
  return thisReading;
}

//--------- MQ-7 carbon monixide sensor ---------
//breakout info: http://citizensensor.cc/make
int getCO(){
  int thisReading = 11;

  if (MQ7.currentState() == LOW){ //not heating, ready to read.
    thisReading = analogRead(CoSensorPin);
  } 
  else { //heating, leave value where it was
    thisReading = currCo;
  }

  return thisReading;
}

//--------- MQ-135 air quality sensor ---------
int getQuality(){
  int thisReading = 12;

  thisReading = analogRead(qualitySensorPin);
  return thisReading;
}

//--------- DHT22 humidity sensor ---------
int getHumidity(){
  int thisReading = 13;

  //thisReading = analogRead(humiditySensorPin);

  float h = dht.readHumidity();

  if (isnan(h)){
    //failed to get reading from DHT
  } 
  else {
    thisReading = int(h);
    return thisReading;
  }
  return thisReading;
}

//--------- DHT22 temperature sensor ---------
int getTemperature(){
  int thisReading = 0;
  /*Wire.requestFrom(tmp102Address,2); 
   
   byte MSB = Wire.read();
   byte LSB = Wire.read();
   
   //it's a 12bit int, using two's compliment for negative
   int TemperatureSum = ((MSB << 8) | LSB) >> 4; 
   
   float celsius = TemperatureSum*0.0625;
   
   thisReading = int(celsius);
   */
  float t = dht.readTemperature();

  if (isnan(t)){
    //failed to get reading from DHT
  } 
  else {
    thisReading = int(t);
    return thisReading;
  }
}

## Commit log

2012-02-15 removed delays, added last successful transmit timer
2012-02-16 added reset timer
2012-04-07 added PCB files, workshop code
    [eggShield.brd, eggShield.sch]
2012-04-08 added .brd, cleaned up
    [eggShield.brd, eggShield.sch]
2012-04-08 cleaned board
    [eggShield.brd]
2012-04-09 fixed RHT pin
    [eggShield.brd, eggShield.sch]
2012-04-09 cleaned up a bit
    [eggShield.brd, eggShield.sch]
2012-05-08 updated sensor circuit, removed unneeded compnts
    [eggShield.brd, eggShield.sch]
2012-05-09 cleaned power circuit
    [eggShield.brd]
2012-05-09 sensor update, needs i2c bus
    [eggShield.brd, eggShield.sch]
2012-05-09 cleaned up
    [eggShield.brd]
2012-05-09 added text
    [eggShield.brd]
2012-05-09 added pdfs
    [eggShield.sch]
2012-05-25 updates to the layout and schematics, bringing in elements of the CMOS breakout module
    [eggShield.brd, eggShield.sch]
2012-05-26 added 2:1 I2C Multiplexer
    [eggShield.brd, eggShield.sch]
2012-05-26 rearranged some layout and routing to improve power filtering
    [eggShield.brd, eggShield.sch]
2012-05-27 some minor changes to component placement, routing, and silk screen
    [eggShield.brd]
2012-05-27 added 4-pin connectors, needs to be checked against cabling; also noticed the range selection resistor taps need to be routed to arduino pins as well
    [eggShield.brd, eggShield.sch]
2012-05-28 added routing for range select signals to arduino header and updated silkscreen for e2v sensors
    [eggShield.brd, eggShield.sch]
2012-05-28 changed DHT22 I/O to DIG2, changed LDO feedback resistor values again, added more documentation to the schematic
    [eggShield.brd, eggShield.sch]
2012-05-28 added registration holes
    [eggShield.brd, eggShield.sch]
2012-05-28 adding solderpad schematic and board images
2012-06-03 major changes incorporating a heater co-processor
    [eggShield.brd, eggShield.sch]
2012-06-12 updated images for solderpad
2012-06-14 incorporated several changes based on review comments
    [eggShield.brd, eggShield.sch]
2012-06-15 updated to make it possible to shut down heaters from coprocessor, added programming header, added analog inputs to measure heater V+, and moved /R2_SEL to accomodate
    [eggShield.brd, eggShield.sch]
2012-06-15 fixed a couple sloppy routes
    [eggShield.brd]
2012-06-20 added barrel jack to shield for 7-15V external power to NAnode
    [eggShield.brd, eggShield.sch]
2012-06-20 added silk screen to barrel jack to make voltage input range and polarity clear
    [eggShield.brd, eggShield.sch]
2012-06-20 deleted registration hole that was sitting out in the middle of nowhere
    [eggShield.brd, eggShield.sch]
2012-07-05 routed DHT22 to A3
    [eggShield.brd, eggShield.sch]
2012-07-05 updated solderpad images
2012-07-16 fixed 2.5v regulator bug
    [eggShield.brd, eggShield.sch]
2012-07-16 picked a more direct route for the 2.5v bug fix
    [eggShield.brd]
2012-08-08 updates to the initial prototype based on testing and feedback. Fixed crossed up digipot lines, rotated the DHT22, move the barrel jack off the headers, replaced 0603s with 0805s.
    [eggShield.brd, eggShield.sch]
2012-08-08 masked vias
    [eggShield.brd]
2012-09-08 production version
    [eggShield.brd, eggShield.sch]
2012-11-18 switched to json
2012-11-20 increased ethernet buffer size, improved stability
    [AQEBase.ino, Nanode.ino, Sensors.ino]
2012-11-21 updated Base sketch to yellow glow the RGB led during pairing
2012-11-21 updated rgb led behavior slightly
2012-12-03 Updated some references from Pachube -> Cosm.
    * updated readme
    * updated api key header name in AQEBase, AQEBaseSensor, and
    AirQualityEggNanode. Didn't change any of the references in the dev or
    AQEWkshop directories or any examples in contained libraries.
    [Sensors.ino, nanode.ino]
2012-12-10 fixed base sensor sketch
    [AQEBaseSensor.ino, Nanode.ino, Provision.ino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]
2013-01-04 fixed negative value bug in radio link sensor value
    [Sensors.ino]
2013-01-29 fixed bug in extrapolation in EggBus library getSensorValue method that was resulting in 0/0 divisions
    [AQERemote.ino]
2013-01-29 rolled version of Base Sensor sketch to note EggBus library changed
2013-01-30 updated sensor polling loop in Remote Egg to fix missing raw values
    [AQERemote.ino]
2013-02-03 added more expressive RGB LED feedback to the startup / initialization process, including pairing feedback
2013-02-05 added check for cosm reply, improved stability
    [AQEBaseSensor.ino, Nanode.ino, Provision.ino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]
2013-02-06 update to auto reset at regular intervals for Wired Base
    [AQEBaseSensor.ino, Sensors.ino]
2013-02-07 separated provisioning from sensor reporting for Wired Egg System
2013-02-07 added zero-crossing fix to EggBus, rolled versions
    [AQEBaseSensor.ino, AQERemote.ino, Sensors.ino]
2013-04-30 added function to retrieve the ADC value and selected low side resistance
2013-05-31 updated softwares to fix problem with provisioning now that xively creates long feed-ids (up to 10 digits), also fixed a minor bug in reporting sensor type for raw feeds on Egg Base sketch
    [AQEBase.ino, AQEBaseSensor.ino, AQEBaseSensorProvision.ino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]
2013-06-04 cosm timeout interval was too short for eggs containng add ons
    [AQEBaseSensor.ino]
2014-04-14 added watchdog timer code and updated to most recent EtherCard library code
2014-04-25 added fallback to static IP if DNS lookup fails, bumped reported version to 2.03
    [AQEBase.ino, Nanode.ino]
2014-04-25 added DNS fail fallback to static IP for Xivly for alternative Egg (Wired Only) configuration
    [AQEBaseSensor.ino, AQEBaseSensorProvision.ino, Nanode.ino]

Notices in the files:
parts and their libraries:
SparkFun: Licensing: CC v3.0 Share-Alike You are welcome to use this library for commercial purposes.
